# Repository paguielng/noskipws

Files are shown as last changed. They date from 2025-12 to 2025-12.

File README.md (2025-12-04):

## Freenove Robot Dog Kit for Raspberry Pi

> A Robot Dog Kit for Raspberry Pi.

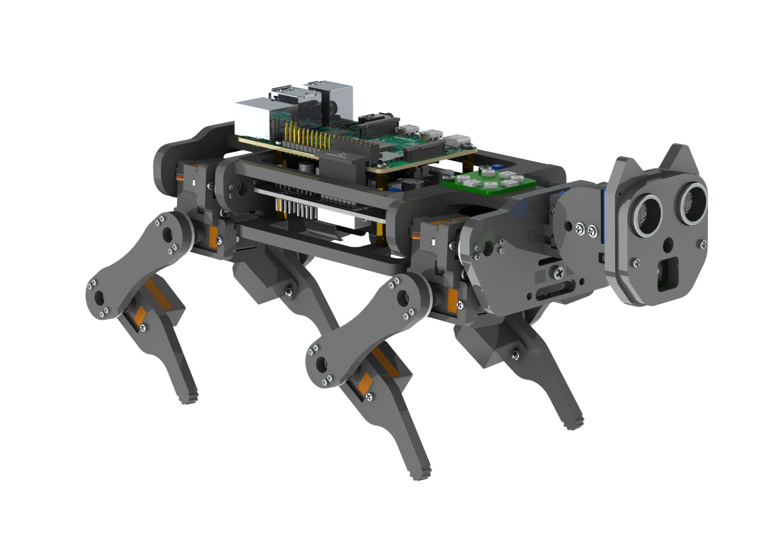
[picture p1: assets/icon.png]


### Connection Board Version

<table>
  <tr>
    <th>PCB Version</th>
    <th>PCB Picture</th>
  </tr>
  <tr>
    <td>V1.0</td>
    <td align="center">
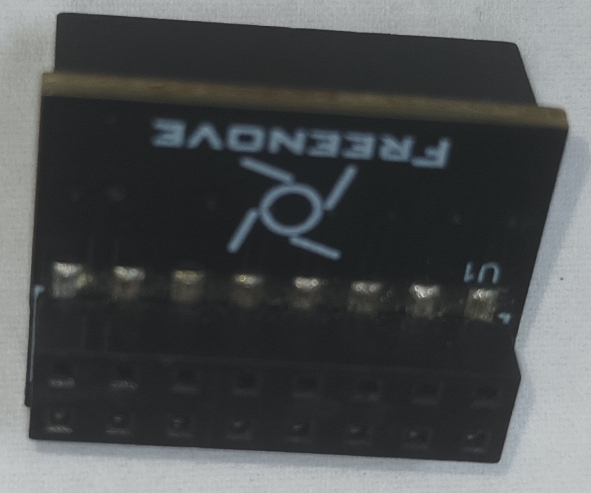
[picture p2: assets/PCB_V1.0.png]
V1.0
      
    </td>
  </tr>
  <tr>
    <td>V2.0</td>
    <td align="center">
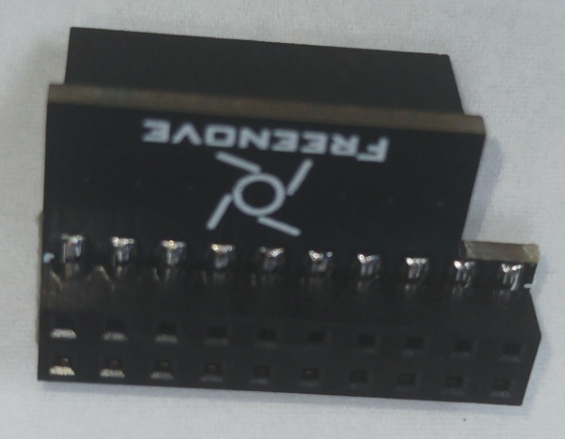
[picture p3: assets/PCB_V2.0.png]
V2.0
      
    </td>
  </tr>
</table>

### Download

* **Use command in console**

	Run following command to download all the files in this repository.

	`git clone https://github.com/Freenove/Freenove_Robot_Dog_Kit_for_Raspberry_Pi.git`

* **Manually download in browser**

	Click the green "Clone or download" button, then click "Download ZIP" button in the pop-up window.
	Do NOT click the "Open in Desktop" button, it will lead you to install Github software.

> If you meet any difficulties, please contact our support team for help.

**Manually download in browser**

	Click the link below "Low Orbit " website, to get a full tutorial of the entire setup.
	
[https://low-orbit.net/freenove-robot-dog-kit-for-raspberry-pi](https://low-orbit.net/freenove-robot-dog-kit-for-raspberry-pi)

### Support

Freenove provides free and quick customer support. Including but not limited to:

* Quality problems of products
* Using Problems of products
* Questions of learning and creation
* Opinions and suggestions
* Ideas and thoughts

Please send an email to:

[support@freenove.com](mailto:support@freenove.com)

We will reply to you within one working day.

### Purchase

Please visit the following page to purchase our products:

http://store.freenove.com

Business customers please contact us through the following email address:

[sale@freenove.com](mailto:sale@freenove.com)

### Copyright

All the files in this repository are released under [Creative Commons Attribution-NonCommercial-ShareAlike 3.0 Unported License](http://creativecommons.org/licenses/by-nc-sa/3.0/).



This means you can use them on your own derived works, in part or completely. But NOT for the purpose of commercial use.
You can find a copy of the license in this repository.

Freenove brand and logo are copyright of Freenove Creative Technology Co., Ltd. Can't be used without formal permission.

### About

Freenove is an open-source electronics platform.

Freenove is committed to helping customer quickly realize the creative idea and product prototypes, making it easy to get started for enthusiasts of programing and electronics and launching innovative open source products.

Our services include:

* Robot kits
* Learning kits for Arduino, Raspberry Pi and micro:bit
* Electronic components and modules, tools
* Product customization service

Our code and circuit are open source. You can obtain the details and the latest information through visiting the following web site:

http://www.freenove.com

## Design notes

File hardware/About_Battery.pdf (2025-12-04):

█ www.freenove.com | About Battery | 1

█ Need help? Contact support@freenove.com

# About Battery

## Important Notes

! Please prepare the right batteries and fully charge them before assembling.
Assembling the robot without right batteries will cause installation errors and damage the servos.

! The control board connected to the USB cable will not charge the batteries. So you aslo need a charger. Almost any charger suitable for 18650 batteries can be used.

## Purchase Links

Please find the battery description and purchase links on the following pages:

https://github.com/Freenove/Freenove_Battery_List/blob/main/18650_Flat-Top_Unprotected.mdhttps://github.com/Freenove/Freenove_Battery_List/blob/main/18650_Button-Top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

! Some links in the list may be invalid, please select other available links or purchase by yourself. ! If you need help or want to report a link failure, please contact support@freenove.com

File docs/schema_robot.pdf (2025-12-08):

# Schéma Électrique Complet – Robot Quadrupède

Schéma Électrique Complet – Robot Quadrupède (Reconstruction Freenove)

1) Vue d’ensemble
- Batteries 2×18650 en série → 7.4 V
- BUCK A : 7.4 V → 5 V (5 A) pour Raspberry Pi + logique
- BUCK B : 7.4 V → 6 V (8 A) pour servos
- PCA9685 : pilotage des 13 servos
- ADS7830 : mesure tension batterie
- MPU6050 : accéléromètre/gyro
- HC-SR04 : ultrason
- WS2812B : LED RGB
- Masse commune sur tous les modules
2) Schéma ASCII

[18650+] --- Fuse10A ---+-------------------+--------------------------+
Switch S1 | Switch S2 | |
BUCK B (6V 8A) | BUCK A (5V 5A) | Raspberry Pi
+6V servos / GND | +5V Pi / GND | |
+--------- GND COMMON -------------------------+

I2C Bus (3.3V):
Pi SDA/SCL → PCA9685 → ADS7830 → MPU6050

Servo connections:
PCA9685 PWM ch0..ch12 → Signal servos
V+ servos ← 6V BUCK B
GND servos ← GND commun

HC-SR04:
Vcc 5V → BUCK A
Trig → GPIO Pi
Echo → Pi via diviseur 10k/20k

WS2812B:
Data → GPIO18 via résistance 330 Ω Vcc 5V → BUCK A
GND commun
3) Notes importantes
- Toujours séparer alimentation servos et Raspberry Pi
- Toujours relier toutes les masses ensemble
- Ajouter condensateur 470 µF sur rail servo +6V
- Ajouter condensateur 1000 µF près des LEDs
- Tester I2C avant de connecter les servos

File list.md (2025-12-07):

[Lien excel des matériaux](https://docs.google.com/spreadsheets/d/1ncy-ci_E_MxiyoKTPBuBzguhb5sRhyd-/edit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)

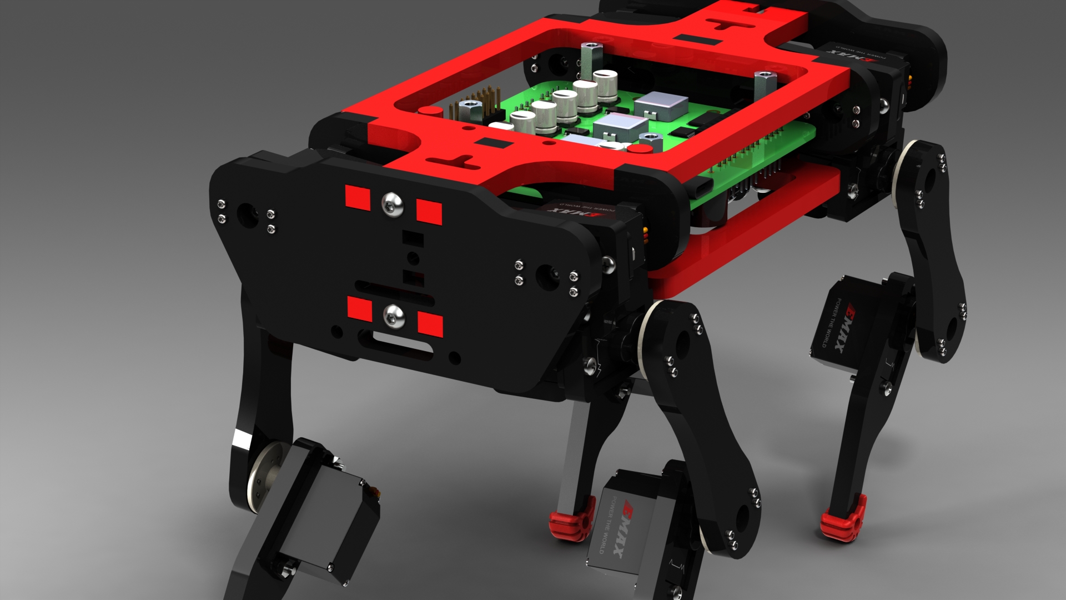
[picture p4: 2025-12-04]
3dmodels/renders/Render_cam2.JPG

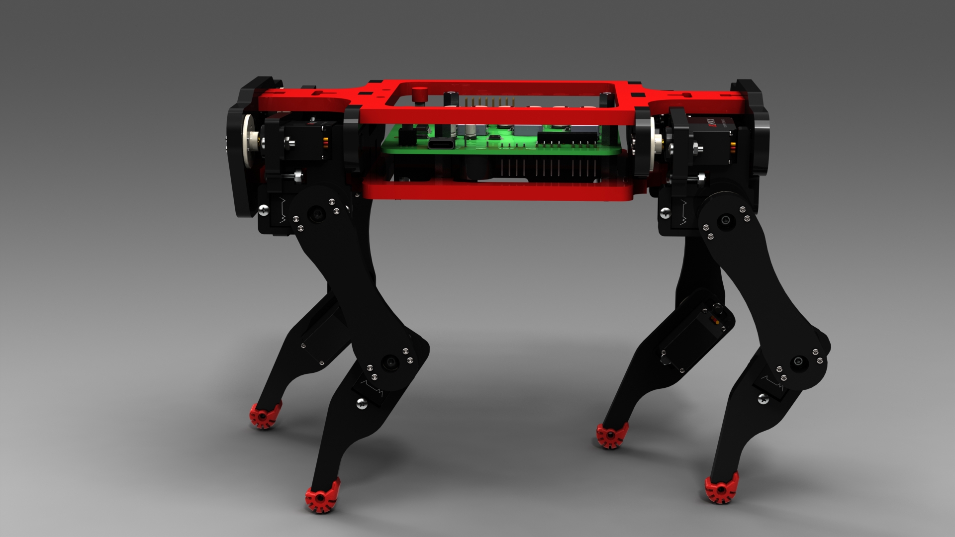
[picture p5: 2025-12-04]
3dmodels/renders/Render_cam4.JPG

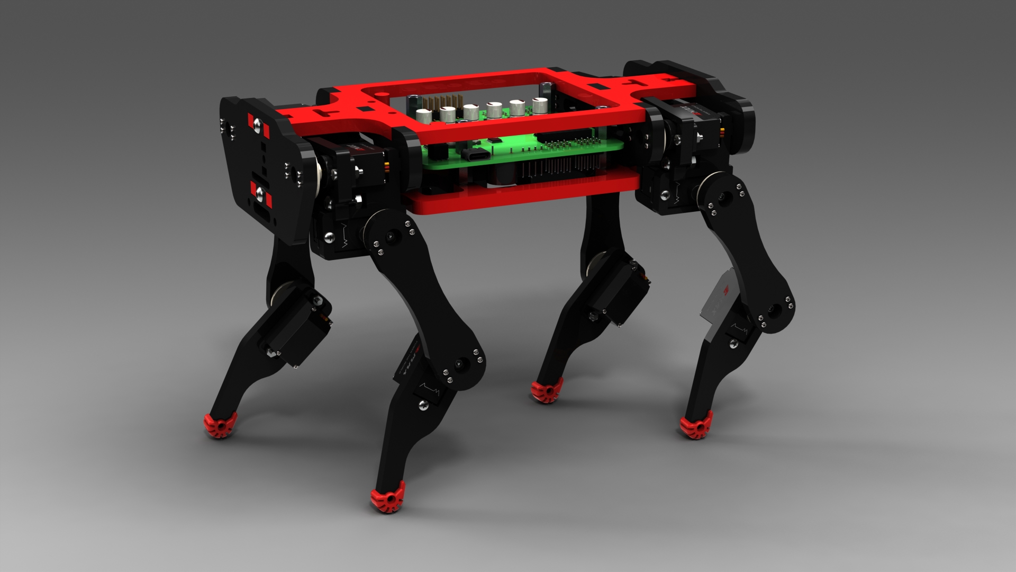
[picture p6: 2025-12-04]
3dmodels/renders/Render_cam1.JPG

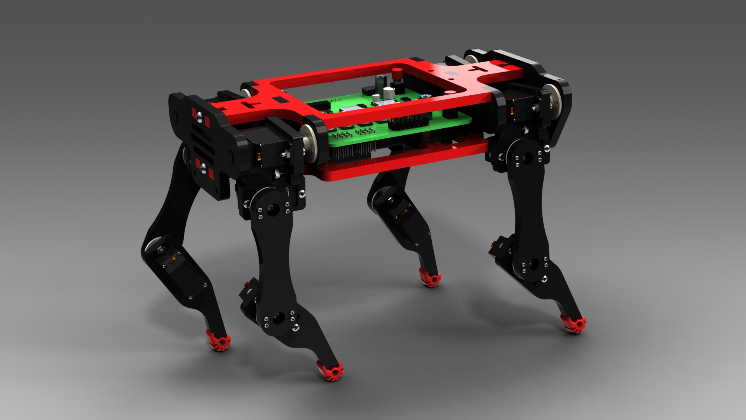
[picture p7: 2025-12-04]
3dmodels/renders/Render_cam3.JPG

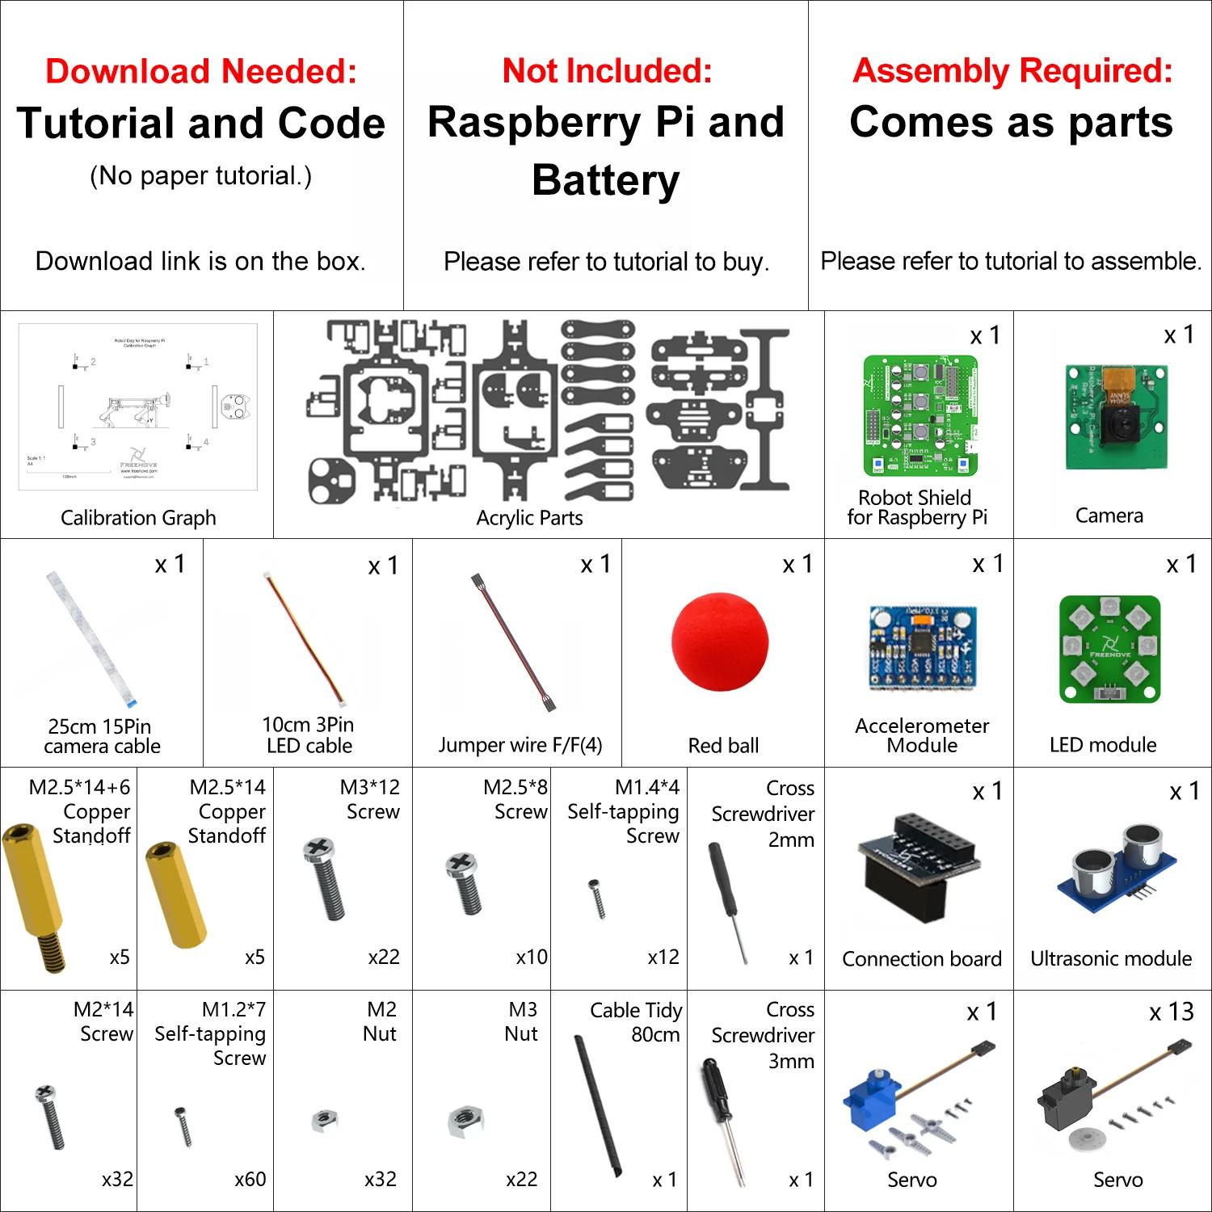
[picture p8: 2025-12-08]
assets/Kit.jpg

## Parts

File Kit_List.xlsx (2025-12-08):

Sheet: Liste complète
Nom | Quantité | Catégorie | Spécifications | Remarques | Prix unitaire | Prix | Fournisseur
Servo ES08MA II | 12 | Transmission | Servo métal 9g, 4.8–6V |  | 1.03 | 12.36 | https://fr.aliexpress.com/item/1005006961093425.html?src=google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
Servo S90 (bleu) | 1 | Transmission | Micro-servo 9g, 4.8–6V |  | 0.99 | 0.99 | https://fr.aliexpress.com/item/1005009456816314.html?src=google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
Vis M1.4*4 ou M1.4*5 | 5 | Machinerie | Acier | Les deux tailles sont compatibles |  | 0
Vis M1.2*7 | 7 | Machinerie | Auto-taraudeuses | Parfois dans le sachet servo |  | 0
M3x12 | 12 | Machinerie | Vis M3 |  | 0.99 | 11.88 | https://fr.aliexpress.com/item/1005006674847139.html?src=google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
Écrous M3 | 12 | Machinerie | Écrous standard M3 |  |  | 0
M2.5x8 | 8 | Machinerie | Vis M2.5 |  |  | 0
Entretoises laiton M2.5x14+6 | 20 | Machinerie | Entretoises hexagonales |  |  | 0
Impression 3D | 3 | 3d impression | Plaques en PETG ou ASA | (plus résistantes que l’acrylique) |  | 0
LED module | 1 | Électronique | WS2812 ou équivalent | optionnel |  | 0
Camera module | 1 | Électronique | Caméra RPi 15 pin |  | 0.99 | 0.99 | https://fr.aliexpress.com/item/1005009258249036.html?src=google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
HC-SR04 | 1 | Électronique | Capteur ultrason 5V |  |  | 0
MPU6050 | 1 | Électronique | Gyro/Accel I2C |  |  | 0
Carte PCB V1.0 ou V2.0 | 1 | Électronique | Shield robot Freenove |  |  | 0
Câble F/F pour ultrasons | 1 | Câbles | Dupont femelle-femelle |  |  | 0
Câble LED 3 pins 10 cm | 1 | Câbles | Même direction |  |  | 0
Câble caméra 25 cm | 1 | Câbles | 15 pin, reversed |  |  | 0
FPC soft line | 1 | Câbles | Version Pi5 |  |  | 0
Tournevis 2mm | 1 | Outils |  |  |  | 0
Tournevis 3mm | 1 | Outils |  |  |  | 0
Cable tidy 80 cm | 1 | Gestion câbles |  |  |  | 0
Carte Raspberry Pi 4B | 1 | Électronique | Raspberry Pi |  |  | 0 | https://www.raspberrypi.com/products/raspberry-pi-4-model-b/
2× Batteries 18650 high drain | 2 | Électronique |  | Batterie Lithium-ion Rechargeable | 0.99 | 1.98 | https://www.aliexpress.com/p/tesla-landing/index.html?scenario=c_ppc_item_bridge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
Support 2×18650 | 1 | Électronique | Support de Batterie |  |  | 0
Step-down 7,4V→6V 8A | 1 | Électronique |  | Alimentation servos | 1.29 | 1.29 | https://fr.aliexpress.com/item/1005006742115510.html
Step-down 7,4V→5V 5A | 1 | Électronique | USB-C / sortie fils | Alimentation Raspberry Pi séparé des servos
Balle rouge | 1 | Accessoire |  |  |  | 0
TOTAL |  |  |  |  |  | 29.49

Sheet: Électronique essentiel
Nom | Quantité | Pourquoi nécessaire | Remarques
PCA9685 – Driver 16 servos, I2C | 1 | Pilotage haute précision pour tes 13 servos | Modèle classique sur breakout board Tension moteurs supportée : 5 à 7,2 V
ADS7830 – ADC 8 bits I2C | 1 | Mesure tension batteries (Freenove l’utilise pour l’indication niveau batterie)
MPU6050 |  | Gyroscope + accéléromètre 6 axes
HC-SR04 |  | Capteur ultrason
LED RGB WS2812B |  | (module 8 LEDs) : optionnel
Caméra Raspberry Pi |  | (V1 ou V2 selon modèle)
Raspberry Pi 4B

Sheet: Électronique de puissance
Nom | Quantité | Pourquoi nécessaire | Remarques
loc Step-Down 7,4 V → 6,0 V 8 A |  | (mieux que le 5 V, car les ES08MA préfèrent 6,0 V)

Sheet: Mécanique
Servos
ES08MA II | 12
S90 (servo bleu) | 1
Visserie
M1.4×4 ou M1.4×5 | 5
M1.2×7 | 7
M3×12 | 12
Écrous M3 | 12
M2.5×8 | 8
Entretoises laiton M2.5×14+6 | 20

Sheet: Pièces manquantes
Nom | Quantité | Pourquoi nécessaire | Remarques
Batteries 18650 high drain (>10A) | 2 | Alimentation principale | Sans PCB de protection
Raspberry Pi 3B+/4B/5 | 1 | Contrôleur principal | Version recommandée : Pi 5

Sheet: Alternatives
Nom original | Alternative | Caractéristiques | Notes
Servo ES08MA II | MG90S | Métal, 4.8–6V | Couple très proche et fiable
Servo S90 | SG90 | Plastique, 4.8–6V | Alternative low cost
HC-SR04 | JSN-SR04T | Étanche, 5V | Plus précis, usage extérieur
MPU6050 | MPU9250 | Gyro+Accel+Magneto | Plus complet
LED module | WS2812B 8 LEDs | RGB adressable | Compatible logiciel
18650 high drain | Samsung 25R | 20A, 2500mAh | Fiable et sûr

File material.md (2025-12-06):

# Guide des matériaux & imprimantes 3D pour le robot Freenove

| Pièce | Matériau recommandé | Imprimante conseillée | Notes |
|---|---|---|---|
| Châssis / Corps | PETG | Bambu Lab P1S / Prusa MK4 | Bon compromis solidité/légèreté |
| Pattes / Articulations | PETG ou ABS/ASA | Bambu Lab P1S (enclosure) / MK4 | Très sollicitées → robustesse |
| Supports de servos | PETG | Toutes Bambu / Prusa | Résistance + stabilité |
| Boîtier batterie | PETG | Toutes Bambu / Prusa | Supporte la chaleur légère |
| Boîtier caméra | PETG | Toutes Bambu / Prusa | Bonne précision et durabilité |
| Clips / Pièces flexibles | TPU 95A | Bambu Lab X1C / Prusa MK4 | Flexibilité nécessaire |
| Supports électroniques | PLA+ ou PETG | Toutes Bambu / Prusa | Peu d'effort mécanique |
| Coins renforcés / pièces fortes| ABS/ASA | Bambu P1S/X1C (enclosure) / MK4 | Très haute résistance |

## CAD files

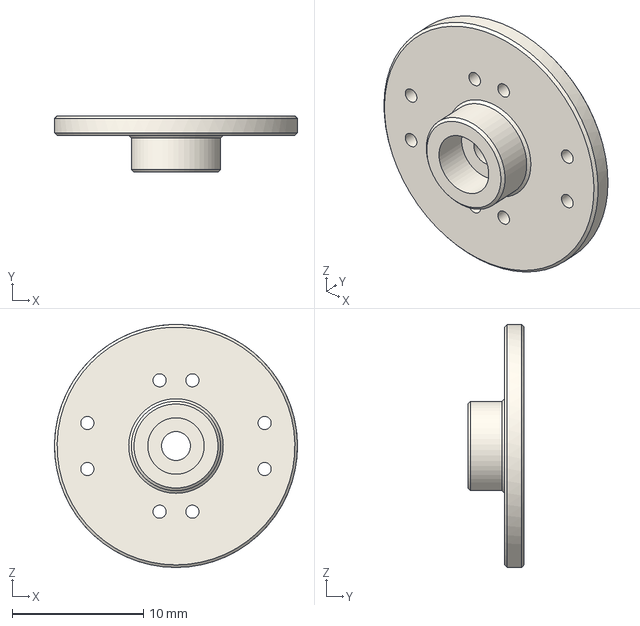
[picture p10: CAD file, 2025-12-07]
3dmodels/12g_9g_disc_horn/12g_9g_disc_horn.step
18.5 x 4.30 x 18.5 mm

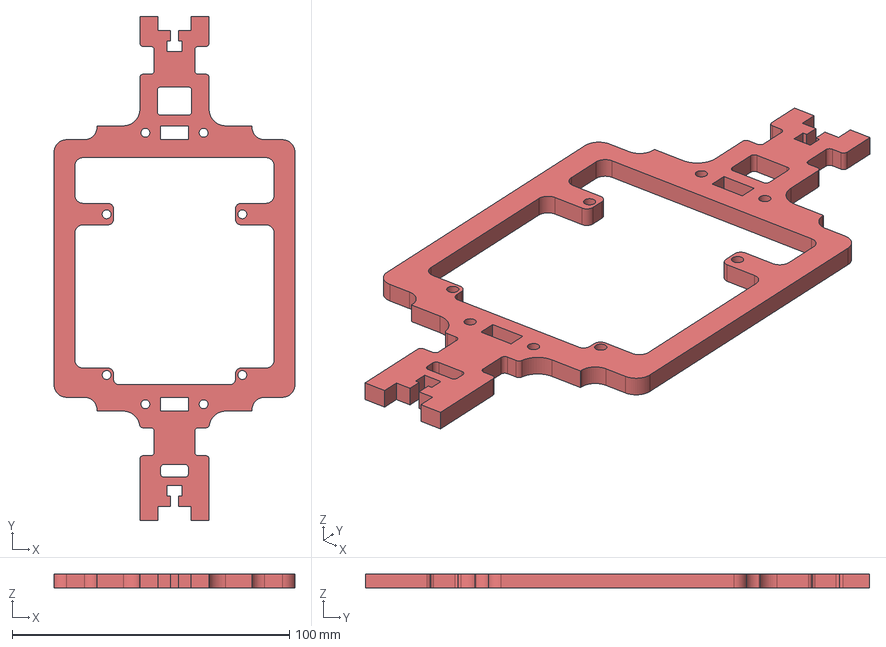
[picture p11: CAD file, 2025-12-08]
3dmodels/Chassis_ASSY/Bottom_baseplate.step
87.0 x 182.0 x 5.00 mm

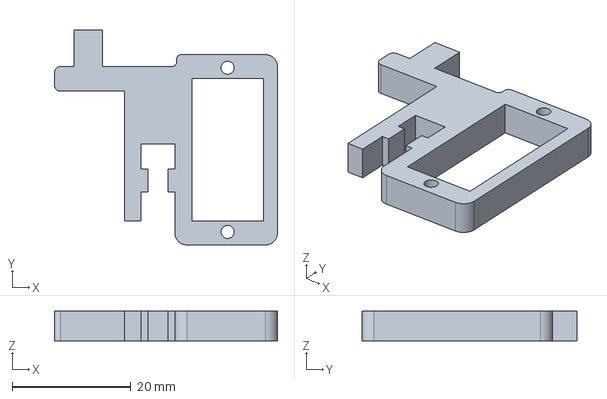
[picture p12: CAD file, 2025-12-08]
3dmodels/Femur/ServoHolder_Ankle.step
37.5 x 36.1 x 5.00 mm

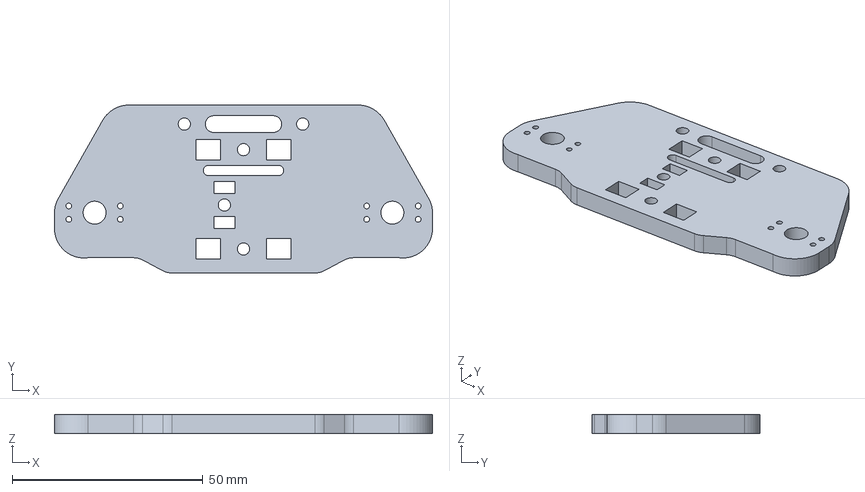
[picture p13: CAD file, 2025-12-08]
3dmodels/FrontPlate_ASSY/Front_SlidePlate.step
99.0 x 44.0 x 5.00 mm

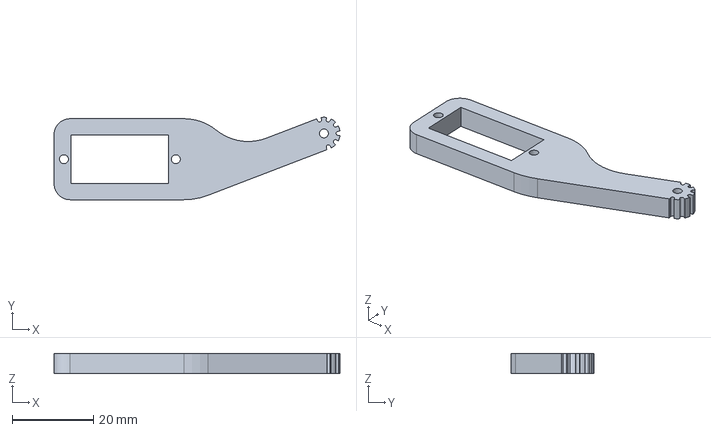
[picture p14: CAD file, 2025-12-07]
3dmodels/tibia/tibia.step
70.5 x 20.4 x 5.00 mm

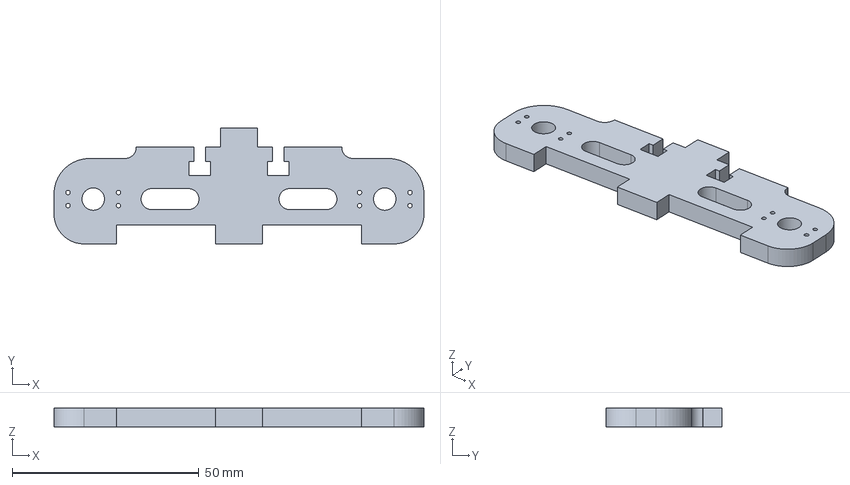
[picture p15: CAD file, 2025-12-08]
3dmodels/Chassis_ASSY/ServoSlideplate_2_1.step
99.0 x 31.0 x 5.00 mm

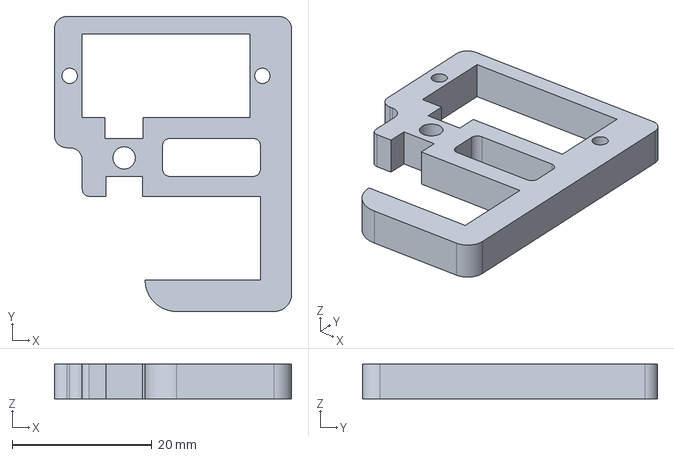
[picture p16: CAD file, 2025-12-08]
3dmodels/Femur/ServoHolder_Femur.step
34.0 x 42.2 x 5.00 mm

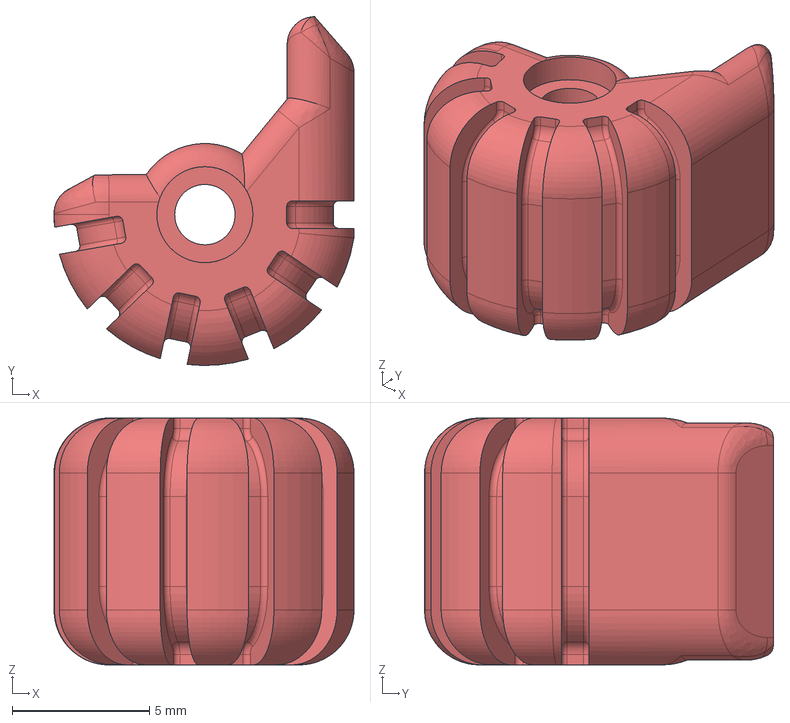
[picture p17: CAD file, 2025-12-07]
3dmodels/rubber_feet.step
10.9 x 12.7 x 9.00 mm

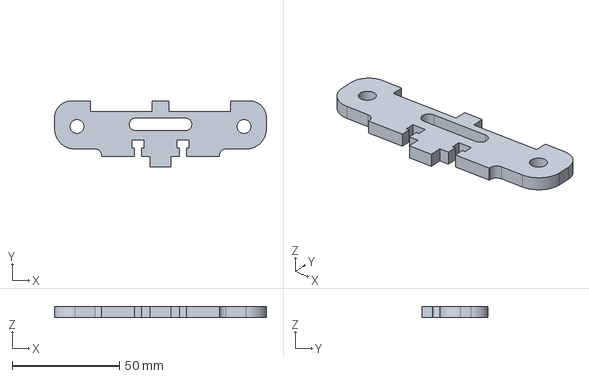
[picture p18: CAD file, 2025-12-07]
3dmodels/Chassis_ASSY/Slideplate_2.step
99.0 x 31.0 x 5.00 mm

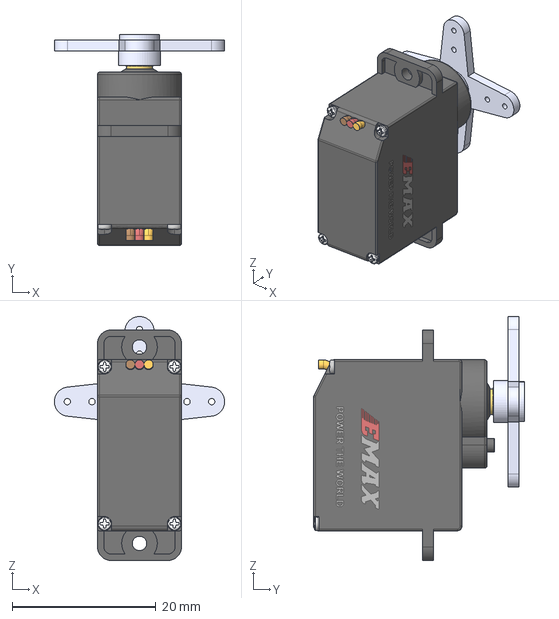
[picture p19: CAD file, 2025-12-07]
3dmodels/EMax ES08MAII Servo.step
23.7 x 29.3 x 33.9 mm

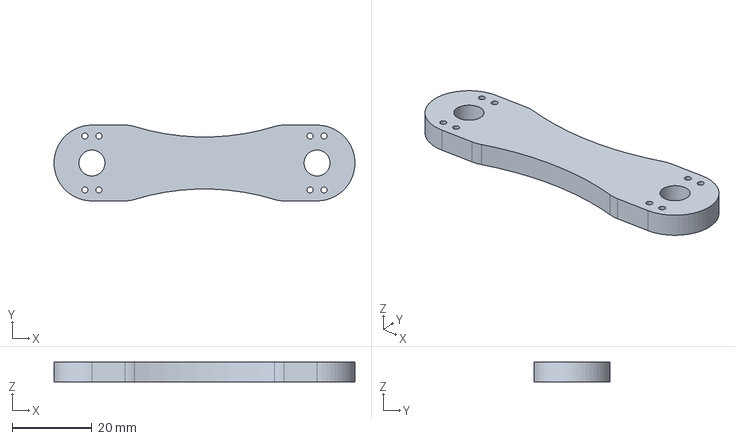
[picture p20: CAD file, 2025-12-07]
3dmodels/Femur/Femur.step
75.4 x 19.0 x 5.00 mm

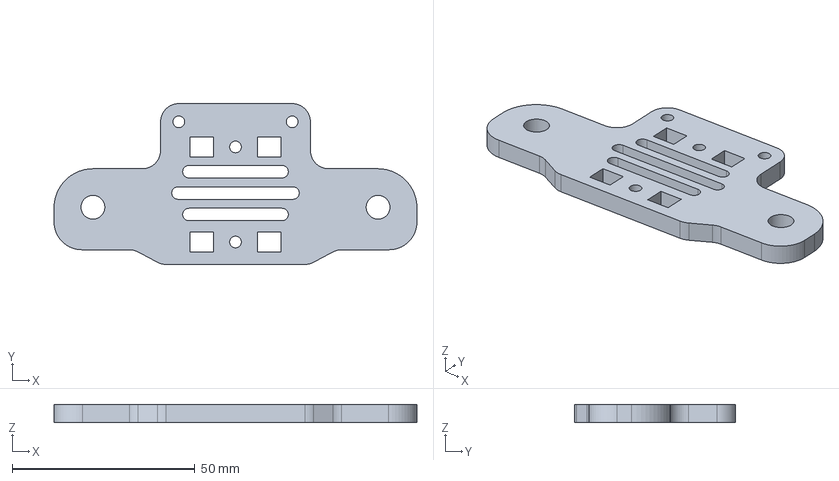
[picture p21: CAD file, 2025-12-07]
3dmodels/Chassis_ASSY/Rear_SlidePlate.step
99.3 x 44.0 x 5.00 mm

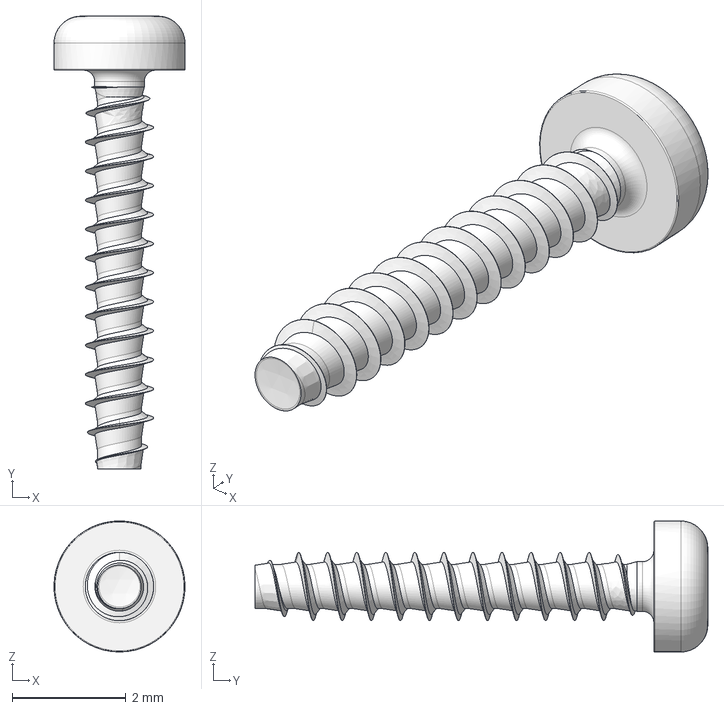
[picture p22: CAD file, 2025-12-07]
3dmodels/torx_1-2_7_STP390120070.step
2.30 x 7.95 x 2.30 mm

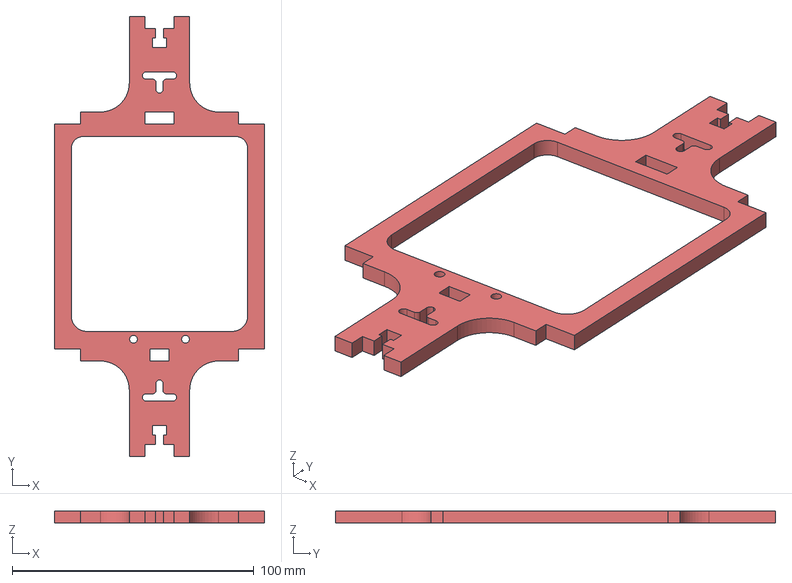
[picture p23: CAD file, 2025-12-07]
3dmodels/Chassis_ASSY/Top_baseplate.step
87.0 x 182.0 x 5.00 mm

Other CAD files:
hardware/Head_Part_2D.dwg
3dmodels/pan head cross recess screw_iso_ISO 7045 - M2 x 10 - Z - 10N.step
3dmodels/socket_button_head screw_iso_ISO 7380 - M3 x 6 - 6N/socket button head screw_iso_ISO 7380 - M3 x 6 - 6N.step
3dmodels/hex nut style 1 gradeab_iso_ISO - 4032 - M2 - W - N.step
3dmodels/12g_9g_disc_horn/12g_9g_disc_horn.stl
3dmodels/Chassis_ASSY/stl/Bottom_baseplate.stl
3dmodels/Chassis_ASSY/stl/Rear_SlidePlate.stl
3dmodels/Chassis_ASSY/stl/ServoSlideplate_2_1.stl
3dmodels/Chassis_ASSY/stl/Slideplate_2.stl
3dmodels/Chassis_ASSY/stl/Top_baseplate.stl
3dmodels/Femur/stl/Femur.stl
3dmodels/Femur/stl/ServoHolder_Ankle.stl
3dmodels/Femur/stl/ServoHolder_Femur.stl
3dmodels/FrontPlate_ASSY/Front_SlidePlate.stl
3dmodels/tibia/tibia.stl

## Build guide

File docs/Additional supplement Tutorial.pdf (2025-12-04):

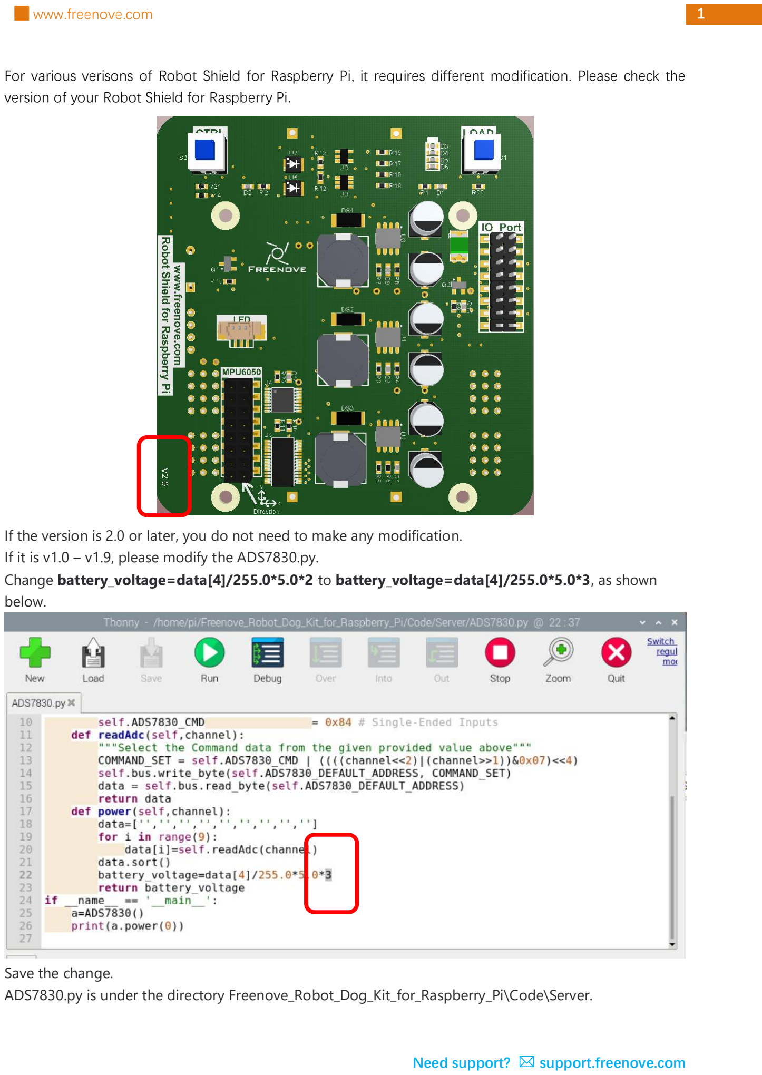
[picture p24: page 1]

Need support? support.freenove.com

█ www.freenove.com | 1

For various verisons of Robot Shield for Raspberry Pi, it requires different modification. Please check the version of your Robot Shield for Raspberry Pi.

If the version is 2.0 or later, you do not need to make any modification.
If it is v1.0 – v1.9, please modify the ADS7830.py.
Change battery_voltage=data[4]/255.0*5.0*2 to battery_voltage=data[4]/255.0*5.0*3, as shown below.

Save the change.
ADS7830.py is under the directory Freenove_Robot_Dog_Kit_for_Raspberry_Pi\Code\Server.

### 2 www.freenove.com █

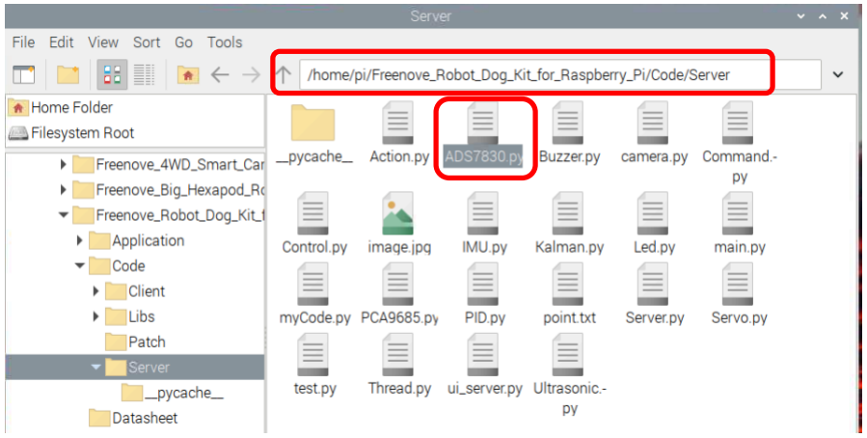
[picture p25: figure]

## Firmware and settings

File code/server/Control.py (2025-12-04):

 # -*- coding: utf-8 -*-
import time
import math
import smbus
import copy
import threading
from IMU import *
from PID import *
import numpy as np
from Servo import *
from Command import COMMAND as cmd

class Control:
    def __init__(self):
        self.run_time_limit = 600        # Limit the running time of the robot dog, beyond which it needs to rest mode for 60 seconds
        self.relax_max_time_limit = 60   # Set the maximum amount of time the robot dog is forced to rest mode
        self.relax_min_time_limit = 10   # Set the time when the robot dog enters the rest mode when there is no operation
        self.imu=IMU()
        self.servo=Servo()
        self.pid = Incremental_PID(0.5,0.0,0.0025)
        self.speed = 8
        self.height = 99
        self.timeout = 0
        self.move_flag = 0
        self.move_count = 0
        self.move_timeout = 0
        self.order = ['','','','','']
        self.point = [[0, 99, 10], [0, 99, 10], [0, 99, -10], [0, 99, -10]]
        self.calibration_point = self.readFromTxt('point')
        self.angle = [[90,0,0],[90,0,0],[90,0,0],[90,0,0]]
        self.calibration_angle=[[0,0,0],[0,0,0],[0,0,0],[0,0,0]]
        self.relax_flag=True
        self.balance_flag=False
        self.attitude_flag=False
        self.Thread_conditiona=threading.Thread(target=self.condition)
        self.calibration()
        self.relax(True)
    def readFromTxt(self,filename):
        file1 = open(filename + ".txt", "r")
        list_row = file1.readlines()
        list_source = []
        for i in range(len(list_row)):
            column_list = list_row[i].strip().split("\t")
            list_source.append(column_list)
        for i in range(len(list_source)):
            for j in range(len(list_source[i])):
                list_source[i][j] = int(list_source[i][j])
        file1.close()
        return list_source

    def saveToTxt(self,list, filename):
        file2 = open(filename + '.txt', 'w')
        for i in range(len(list)):
            for j in range(len(list[i])):
                file2.write(str(list[i][j]))
                file2.write('\t')
            file2.write('\n')
        file2.close()
        
    def coordinateToAngle(self,x,y,z,l1=23,l2=55,l3=55):
        a=math.pi/2-math.atan2(z,y)
        x_3=0
        x_4=l1*math.sin(a)
        x_5=l1*math.cos(a)
        l23=math.sqrt((z-x_5)**2+(y-x_4)**2+(x-x_3)**2)
        w=(x-x_3)/l23
        v=(l2*l2+l23*l23-l3*l3)/(2*l2*l23)
        b=math.asin(round(w,2))-math.acos(round(v,2))
        c=math.pi-math.acos(round((l2**2+l3**2-l23**2)/(2*l3*l2),2))
        a=round(math.degrees(a))
        b=round(math.degrees(b))
        c=round(math.degrees(c))
        return a,b,c
    
    def angleToCoordinate(self,a,b,c,l1=23,l2=55,l3=55):
        a=math.pi/180*a
        b=math.pi/180*b
        c=math.pi/180*c
        x=l3*math.sin(b+c)+l2*math.sin(b)
        y=l3*math.sin(a)*math.cos(b+c)+l2*math.sin(a)*math.cos(b)+l1*math.sin(a)
        z=l3*math.cos(a)*math.cos(b+c)+l2*math.cos(a)*math.cos(b)+l1*math.cos(a)
        return x,y,z
    
    def calibration(self):
        for i in range(4):
            self.calibration_angle[i][0],self.calibration_angle[i][1],self.calibration_angle[i][2]=self.coordinateToAngle(self.calibration_point[i][0],
                                                                                                                          self.calibration_point[i][1],
                                                                                                                          self.calibration_point[i][2])
        for i in range(4):
            self.angle[i][0],self.angle[i][1],self.angle[i][2]=self.coordinateToAngle(self.point[i][0],
                                                                                      self.point[i][1],
                                                                                      self.point[i][2])
        for i in range(4):
            self.calibration_angle[i][0]=self.calibration_angle[i][0]-self.angle[i][0]
            self.calibration_angle[i][1]=self.calibration_angle[i][1]-self.angle[i][1]
            self.calibration_angle[i][2]=self.calibration_angle[i][2]-self.angle[i][2]
    def run(self):
        if self.checkPoint():
            try:
                for i in range(4):
                    self.angle[i][0],self.angle[i][1],self.angle[i][2]=self.coordinateToAngle(self.point[i][0],
                                                                                              self.point[i][1],
                                                                                              self.point[i][2])
                for i in range(2):
                    self.angle[i][0]=self.restriction(self.angle[i][0]+self.calibration_angle[i][0],0,180)
                    self.angle[i][1]=self.restriction(90-(self.angle[i][1]+self.calibration_angle[i][1]),0,180)
                    self.angle[i][2]=self.restriction(self.angle[i][2]+self.calibration_angle[i][2],0,180)
                    self.angle[i+2][0]=self.restriction(self.angle[i+2][0]+self.calibration_angle[i+2][0],0,180)
                    self.angle[i+2][1]=self.restriction(90+self.angle[i+2][1]+self.calibration_angle[i+2][1],0,180)
                    self.angle[i+2][2]=self.restriction(180-(self.angle[i+2][2]+self.calibration_angle[i+2][2]),0,180)
                for i in range(2):
                    self.servo.setServoAngle(4+i*3,self.angle[i][0])
                    self.servo.setServoAngle(3+i*3,self.angle[i][1])
                    self.servo.setServoAngle(2+i*3,self.angle[i][2])
                    self.servo.setServoAngle(8+i*3,self.angle[i+2][0])
                    self.servo.setServoAngle(9+i*3,self.angle[i+2][1])
                    self.servo.setServoAngle(10+i*3,self.angle[i+2][2])
            except Exception as e:
                pass
        else:
            print("This coordinate point is out of the active range")
    def checkPoint(self):
        flag=True
        leg_lenght=[0,0,0,0,0,0]  
        for i in range(4):
          leg_lenght[i]=math.sqrt(self.point[i][0]**2+self.point[i][1]**2+self.point[i][2]**2)
        for i in range(4         ):
          if leg_lenght[i] > 130 or leg_lenght[i] < 25:
            flag=False
        return flag
            
    def condition(self):
        while True:
            try:
                if time.time()-self.move_timeout > self.relax_max_time_limit and self.move_timeout!=0 and self.relax_flag==True:
                    self.move_count=0
                    self.move_timeout=time.time()
                if self.move_count < self.run_time_limit:
                    if (time.time()-self.timeout)>self.relax_min_time_limit and self.timeout!=0 and self.relax_flag==False and self.order[0] == '':
                        self.timeout=time.time()
                        self.relax_flag=True
                        self.relax(True)
                        self.order=['','','','','']
                    if self.relax_flag==True and self.order[0] != ''  and self.order[0] !=cmd.CMD_RELAX: 
                        self.relax(False)
                        self.relax_flag=False
                    if self.attitude_flag==True and self.order[0] != cmd.CMD_ATTITUDE and self.order[0] != '':
                        self.stop()   
                        self.attitude_flag=False  
                    if self.relax_flag==False: 
                        self.move_count+=time.time()-self.move_timeout
                        self.move_timeout=time.time()
                    if self.order[0]==cmd.CMD_MOVE_STOP:
                        self.order=['','','','','']
                        self.stop()
                    elif self.order[0]==cmd.CMD_MOVE_FORWARD:
                        self.speed=int(self.order[1])
                        self.forWard()
                    elif self.order[0]==cmd.CMD_MOVE_BACKWARD:
                        self.speed=int(self.order[1])
                        self.backWard()
                    elif self.order[0]==cmd.CMD_MOVE_LEFT:
                        self.speed=int(self.order[1])
                        self.setpLeft()
                    elif self.order[0]==cmd.CMD_MOVE_RIGHT:
                        self.speed=int(self.order[1])
                        self.setpRight()
                    elif self.order[0]==cmd.CMD_TURN_LEFT:
                        self.speed=int(self.order[1])
                        self.turnLeft()
                    elif self.order[0]==cmd.CMD_TURN_RIGHT:
                        self.speed=int(self.order[1])
                        self.turnRight()
                    elif self.order[0]==cmd.CMD_RELAX:
                        if self.relax_flag:
                            self.relax_flag=False
                            self.relax(False)
                        else:
                            self.relax_flag=True
                            self.relax(True)
                        self.order=['','','','','']
                    elif self.order[0]==cmd.CMD_HEIGHT:
                        self.upAndDown(int(self.order[1]))
                        self.order=['','','','','']
                    elif self.order[0]==cmd.CMD_HORIZON:
                        self.beforeAndAfter(int(self.order[1]))
                        self.order=['','','','','']
                    elif self.order[0]==cmd.CMD_ATTITUDE:
                        self.attitude_flag=True
                        self.attitude(self.order[1],self.order[2],self.order[3])
                    elif self.order[0]==cmd.CMD_CALIBRATION:
                        self.move_count=0
                        if self.order[1]=="one":
                            self.calibration_point[0][0]=int(self.order[2])
                            self.calibration_point[0][1]=int(self.order[3])
                            self.calibration_point[0][2]=int(self.order[4])
                            self.calibration()
                            self.run()
                        elif self.order[1]=="two":
                            self.calibration_point[1][0]=int(self.order[2])
                            self.calibration_point[1][1]=int(self.order[3])
                            self.calibration_point[1][2]=int(self.order[4])
                            self.calibration()
                            self.run()
                        elif self.order[1]=="three":
                            self.calibration_point[2][0]=int(self.order[2])
                            self.calibration_point[2][1]=int(self.order[3])
                            self.calibration_point[2][2]=int(self.order[4])
                            self.calibration()
                            self.run()   
                        elif self.order[1]=="four":
                            self.calibration_point[3][0]=int(self.order[2])
                            self.calibration_point[3][1]=int(self.order[3])
                            self.calibration_point[3][2]=int(self.order[4])
                            self.calibration()
                            self.run()
                        elif self.order[1]=="save":
                            self.saveToTxt(self.calibration_point,'point')
                            self.stop()
                    elif self.order[0]==cmd.CMD_BALANCE and self.order[1]=='1':
                        Thread_IMU=threading.Thread(target=self.IMU6050())
                        Thread_IMU.start()
                        break
                elif self.move_count > self.run_time_limit :
                    self.relax_flag=True
                    self.relax(True)
                    if self.move_flag!=1:
                        self.move_flag=1
                    if  self.move_count > (self.run_time_limit+self.relax_max_time_limit):
                        self.move_count=0
                        self.move_flag=0
                    self.order=['','','','','']
            except Exception as e:
                print(e)
    def restriction(self,var,v_min,v_max):
        if var < v_min:
            return v_min
        elif var > v_max:
            return v_max
        else:
            return var            
    def map(self,value,fromLow,fromHigh,toLow,toHigh):
        return (toHigh-toLow)*(value-fromLow) / (fromHigh-fromLow) + toLow
    def changeCoordinates(self,move_order,X1=0,Y1=96,Z1=0,X2=0,Y2=96,Z2=0,pos=np.asmatrix(np.zeros((3, 4)))):
        if move_order == 'turnLeft':  
            for i in range(2):
                self.point[2*i][0]=((-1)**(1+i))*X1+10
                self.point[2*i][1]=Y1
                self.point[2*i][2]=((-1)**(i))*Z1+((-1)**i)*10
                self.point[1+2*i][0]=((-1)**(1+i))*X2+10
                self.point[1+2*i][1]=Y2
                self.point[1+2*i][2]=((-1)**(1+i))*Z2+((-1)**i)*10
        elif move_order == 'turnRight': 
            for i in range(2):
                self.point[2*i][0]=((-1)**(i))*X1+10
                self.point[2*i][1]=Y1
                self.point[2*i][2]=((-1)**(1+i))*Z1+((-1)**i)*10
                self.point[1+2*i][0]=((-1)**(i))*X2+10
                self.point[1+2*i][1]=Y2
                self.point[1+2*i][2]=((-1)**(i))*Z2+((-1)**i)*10
        elif (move_order == 'height') or (move_order == 'horizon'):   
            for i in range(2):
                self.point[3*i][0]=X1+10
                self.point[3*i][1]=Y1
                self.point[1+i][0]=X2+10
                self.point[1+i][1]=Y2
        elif move_order == 'Attitude Angle': 
            for i in range(2):
                self.point[3-i][0]=pos[0,1+2*i]+10
                self.point[3-i][1]=pos[2,1+2*i]
                self.point[3-i][2]=pos[1,1+2*i]      
                self.point[i][0]=pos[0,2*i]+10
                self.point[i][1]=pos[2,2*i]
                self.point[i][2]=pos[1,2*i]
        else: #'backWard' 'forWard' 'setpRight' 'setpLeft'
            for i in range(2):
                self.point[i*2][0]=X1+10
                self.point[i*2][1]=Y1
                self.point[i*2+1][0]=X2+10
                self.point[i*2+1][1]=Y2
                self.point[i*2][2]=Z1+((-1)**i)*10
                self.point[i*2+1][2]=Z2+((-1)**i)*10
        self.run()
    def backWard(self):
        for i in range(450,89,-self.speed):
            X1=12*math.cos(i*math.pi/180)
            Y1=6*math.sin(i*math.pi/180)+self.height
            X2=12*math.cos((i+180)*math.pi/180)
            Y2=6*math.sin((i+180)*math.pi/180)+self.height
            if Y2 > self.height:
                Y2=self.height
            if Y1 > self.height:
                Y1=self.height
            self.changeCoordinates('backWard',X1,Y1,0,X2,Y2,0)
            #time.sleep(0.01)
    def forWard(self):
        for i in range(90,451,self.speed):
            X1=12*math.cos(i*math.pi/180)
            Y1=6*math.sin(i*math.pi/180)+self.height
            X2=12*math.cos((i+180)*math.pi/180)
            Y2=6*math.sin((i+180)*math.pi/180)+self.height
            if Y2 > self.height:
                Y2=self.height
            if Y1 > self.height:
                Y1=self.height
            self.changeCoordinates('forWard',X1,Y1,0,X2,Y2,0)
            #time.sleep(0.01)
    def turnLeft(self):
        for i in range(0,361,self.speed):
            X1=3*math.cos(i*math.pi/180)
            Y1=8*math.sin(i*math.pi/180)+self.height
            X2=3*math.cos((i+180)*math.pi/180)
            Y2=8*math.sin((i+180)*math.pi/180)+self.height
            if Y2 > self.height:
                Y2=self.height
            if Y1 > self.height:
                Y1=self.height
            Z1=X1
            Z2=X2
            self.changeCoordinates('turnLeft',X1,Y1,Z1,X2,Y2,Z2)
            #time.sleep(0.01)
    
    def turnRight(self):
         for i in range(0,361,self.speed):
            X1=3*math.cos(i*math.pi/180)
            Y1=8*math.sin(i*math.pi/180)+self.height
            X2=3*math.cos((i+180)*math.pi/180)
            Y2=8*math.sin((i+180)*math.pi/180)+self.height
            if Y2 > self.height:
                Y2=self.height
            if Y1 > self.height:
                Y1=self.height
            Z1=X1
            Z2=X2
            self.changeCoordinates('turnRight',X1,Y1,Z1,X2,Y2,Z2)  
            #time.sleep(0.01)
    def stop(self):
        p=[[10, self.height, 10], [10, self.height, 10], [10, self.height, -10], [10, self.height, -10]]
        for i in range(4):
            p[i][0]=(p[i][0]-self.point[i][0])/50
            p[i][1]=(p[i][1]-self.point[i][1])/50
            p[i][2]=(p[i][2]-self.point[i][2])/50
        for j in range(50):
            for i in range(4):
                self.point[i][0]+=p[i][0]
                self.point[i][1]+=p[i][1]
                self.point[i][2]+=p[i][2]
            self.run()
    def setpLeft(self):
        for i in range(90,451,self.speed):
            Z1=10*math.cos(i*math.pi/180)
            Y1=5*math.sin(i*math.pi/180)+self.height
            Z2=10*math.cos((i+180)*math.pi/180)
            Y2=5*math.sin((i+180)*math.pi/180)+self.height
            if Y1 > self.height:
                Y1=self.height
            if Y2 > self.height:
                Y2=self.height
            self.changeCoordinates('setpLeft',0,Y1,Z1,0,Y2,Z2)
            #time.sleep(0.01)
    def setpRight(self):
        for i in range(450,89,-self.speed):
            Z1=10*math.cos(i*math.pi/180)
            Y1=5*math.sin(i*math.pi/180)+self.height
            Z2=10*math.cos((i+180)*math.pi/180)
            Y2=5*math.sin((i+180)*math.pi/180)+self.height
            if Y1 > self.height:
                Y1=self.height
            if Y2 > self.height:
                Y2=self.height
            self.changeCoordinates('setpRight',0,Y1,Z1,0,Y2,Z2)
            #time.sleep(0.01)
    def relax(self,flag=False):
        if flag==True:
            p=[[55, 78, 0], [55, 78, 0], [55, 78, 0], [55, 78, 0]]
            for i in range(4):
                p[i][0]=(self.point[i][0]-p[i][0])/50
                p[i][1]=(self.point[i][1]-p[i][1])/50
                p[i][2]=(self.point[i][2]-p[i][2])/50
            for j in range(1,51):
                for i in range(4):
                    self.point[i][0]-=p[i][0]
                    self.point[i][1]-=p[i][1]
                    self.point[i][2]-=p[i][2]
                self.run()
            if self.move_timeout!=0:
                self.move_count+=time.time()-self.move_timeout
                self.move_timeout=time.time()
        else:
            self.stop()
            self.move_timeout=time.time()
    def upAndDown(self,var):
        self.height=var+99
        self.changeCoordinates('height',0,self.height,0,0,self.height,0)
    def beforeAndAfter(self,var):
        self.changeCoordinates('horizon',var,self.height,0,var,self.height,0)
    def attitude(self,r,p,y):
        r=self.map(int(r),-20,20,-10,10)
        p=self.map(int(p),-20,20,-10,10)
        y=self.map(int(y),-20,20,-10,10)
        pos=self.postureBalance(r,p,y,0)
        self.changeCoordinates('Attitude Angle',pos=pos)
    def IMU6050(self):
        self.balance_flag=True
        self.order=['','','','','']
        pos=self.postureBalance(0,0,0)
        self.changeCoordinates('Attitude Angle',pos=pos)
        time.sleep(2)
        self.imu.Error_value_accel_data,self.imu.Error_value_gyro_data=self.imu.average_filter()
        time.sleep(1)
        while True:
            self.move_count+=time.time()-self.move_timeout
            self.move_timeout=time.time()
            r,p,y=self.imu.imuUpdate()
            r=self.pid.PID_compute(r)
            p=self.pid.PID_compute(p)
            pos=self.postureBalance(r,p,0)
            self.changeCoordinates('Attitude Angle',pos=pos)
            if  (self.order[0]==cmd.CMD_BALANCE and self.order[1]=='0')or(self.balance_flag==True and self.order[0]!='')or(self.move_count>self.run_time_limit):
                Thread_conditiona=threading.Thread(target=self.condition)
                Thread_conditiona.start()
                self.balance_flag==False
                break
    def postureBalance(self,r,p,y,h=1):
        b = 76
        w = 76
        l = 136
        if h!=0:
            h=self.height
        pos = np.mat([0.0,  0.0,  h ]).T 
        rpy = np.array([r,  p,  y]) * math.pi / 180 
        R, P, Y = rpy[0], rpy[1], rpy[2]
        rotx = np.mat([[ 1,       0,            0          ],
                     [ 0,       math.cos(R), -math.sin(R)],
                     [ 0,       math.sin(R),  math.cos(R)]])
        roty = np.mat([[ math.cos(P),  0,      -math.sin(P)],
                     [ 0,            1,       0          ],
                     [ math.sin(P),  0,       math.cos(P)]]) 
        rotz = np.mat([[ math.cos(Y), -math.sin(Y),  0     ],
                     [ math.sin(Y),  math.cos(Y),  0     ],
                     [ 0,            0,            1     ]])
        rot_mat = rotx * roty * rotz
        body_struc = np.mat([[ l / 2,  b / 2,  0],
                           [ l / 2, -b / 2,    0],
                           [-l / 2,  b / 2,    0],
                           [-l / 2, -b / 2,    0]]).T
        footpoint_struc = np.mat([[(l / 2),  (w / 2)+10,  self.height-h],
                                [ (l / 2), (-w / 2)-10,    self.height-h],
                                [(-l / 2),  (w / 2)+10,    self.height-h],
                                [(-l / 2), (-w / 2)-10,    self.height-h]]).T
        AB = np.mat(np.zeros((3, 4)))
        for i in range(4):
            AB[:, i] = pos + rot_mat * footpoint_struc[:, i] - body_struc[:, i]
        return (AB)
        
if __name__=='__main__':
    pass

        
   

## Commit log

2025-12-04 Premier commit
    [Head_Part_2D.dwg, config.txt]
2025-12-04 Update and rename Leg_Type1_ASSY1.step to Leg_Type1_ASSYcvjh;bk1.step
    [Leg_Type1_ASSYcvjh;bk1.step]
2025-12-05 renomme
    renomme dossier software en code
    [config.txt]
2025-12-07 Add link to materials Excel sheet in list.md
    Added a link to an Excel sheet containing material details.
2025-12-08 Update and rename 3dmodels/Front_SlidePlate.step to 3dmodels/FrontPlate_ASSY/Front_SlidePlate.step
    [Front_SlidePlate.step]
2025-12-08 Update and rename 3dmodels/Femur.step to 3dmodels/Femur/Femur.step
    [Femur.step]
2025-12-08 Update and rename 3dmodels/tibia.step to 3dmodels/tibia/tibia.step
    [tibia.step]
2025-12-11 Update and rename 3dmodels/12g_9g_disc_horn.step to 3dmodels/12g_9g_disc_horn/12g_9g_disc_horn.step
    [12g_9g_disc_horn.step]
